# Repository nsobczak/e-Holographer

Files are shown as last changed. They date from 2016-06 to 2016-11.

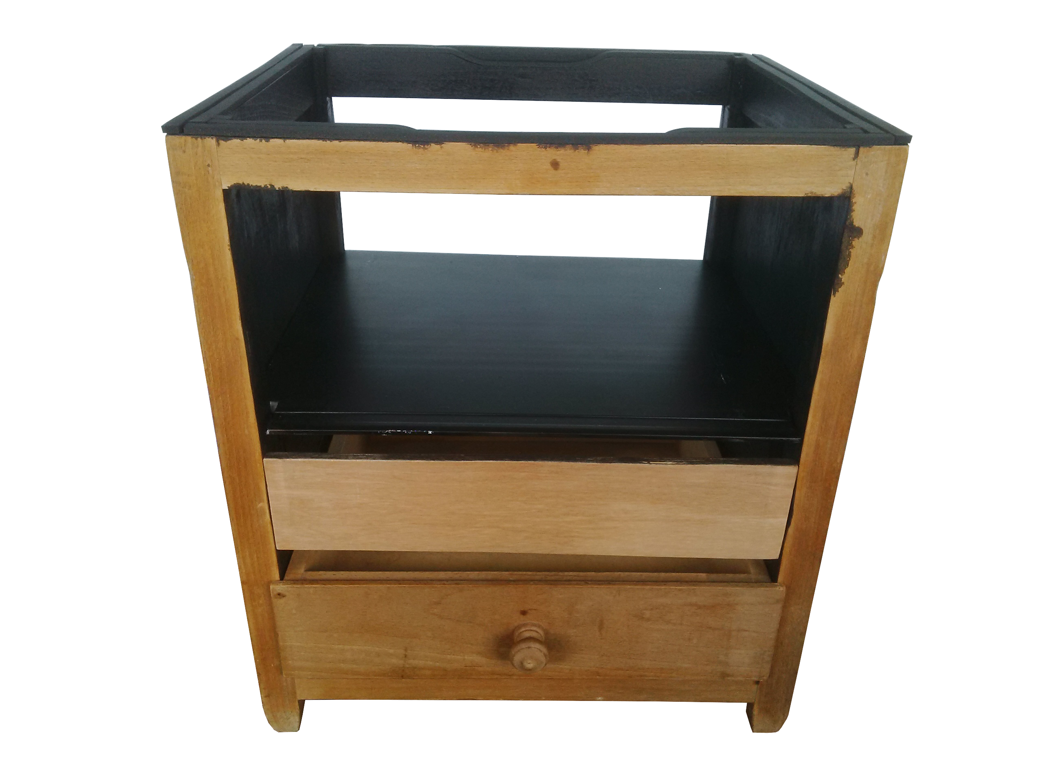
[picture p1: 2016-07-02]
Images/Armature e-Holographer.png

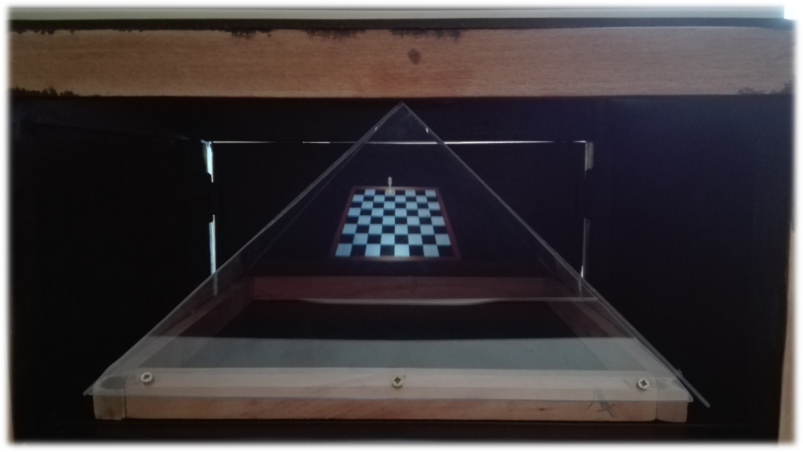
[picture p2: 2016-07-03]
Images/ChessGame/JeuDechec.jpg

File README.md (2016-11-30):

# e-Holographer

Le e-Holographer est un objet connecté permettant d'afficher des hologrammes. Il peut être intégré dans toutes sortes d'applications. Nous avons choisi de développer un jeu d'échec pour le mettre en avant les possibilités de notre e-Holographer. 

Pour plus d'informations, un [wiki](https://github.com/nsobczak/e-Holographer/wiki) est disponible

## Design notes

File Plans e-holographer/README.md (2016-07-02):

#Plans

Nous avons utilisé le logiciel Solidworks pour modéliser notre e-Holographer et générer les plans nécessaires à sa construction.

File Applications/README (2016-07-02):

Ce dossier est destiné à accueillir toutes les applications du e-Holographer.

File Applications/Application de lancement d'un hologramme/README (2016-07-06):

Dossier de l'application du tuto : lancement d'un hologramme.

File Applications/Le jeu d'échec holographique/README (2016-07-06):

Dossier de l'application jeu d'échec holographique.

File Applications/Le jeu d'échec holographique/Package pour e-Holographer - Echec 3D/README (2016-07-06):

Package constellation à déployer sur la sentinelle e-Holographer.

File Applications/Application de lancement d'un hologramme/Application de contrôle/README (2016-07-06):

Application de contrôle. Il s'agit d'une application Androïd créé avec Cordova.

Les scripts se trouvent dans le dossier "www"
L'apk se trouve dans platforms/android/build/outputs/apk

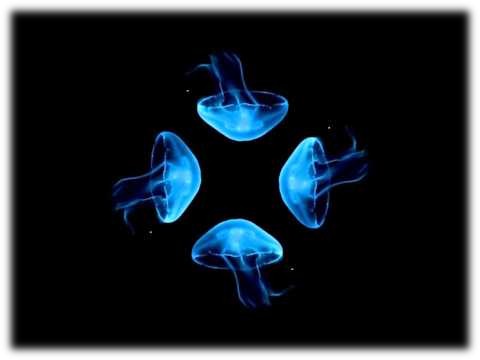
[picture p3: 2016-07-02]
Images/ImageMeduse.jpg

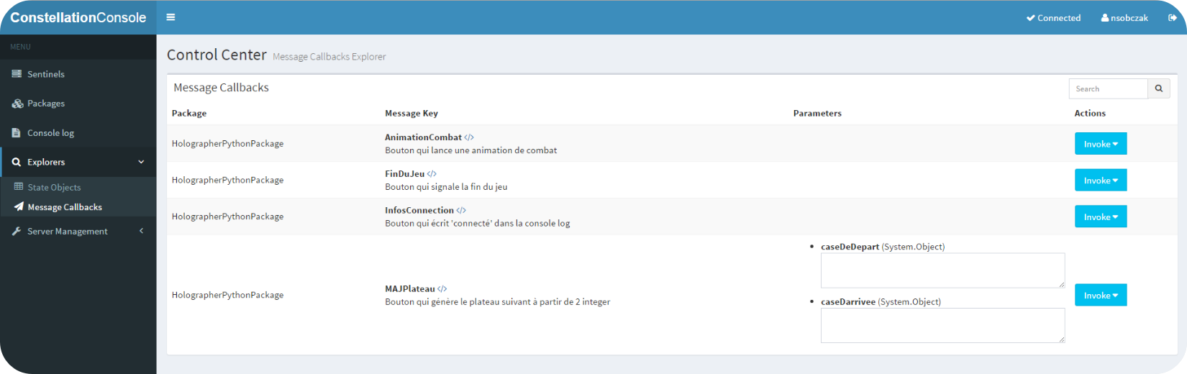
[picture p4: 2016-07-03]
Images/ChessGame/Capture_ConstellationConsole_MC.png

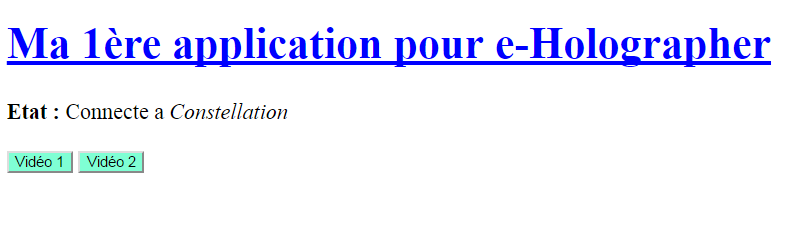
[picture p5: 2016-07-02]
Images/Ma 1ère application pour e-Holographer.PNG

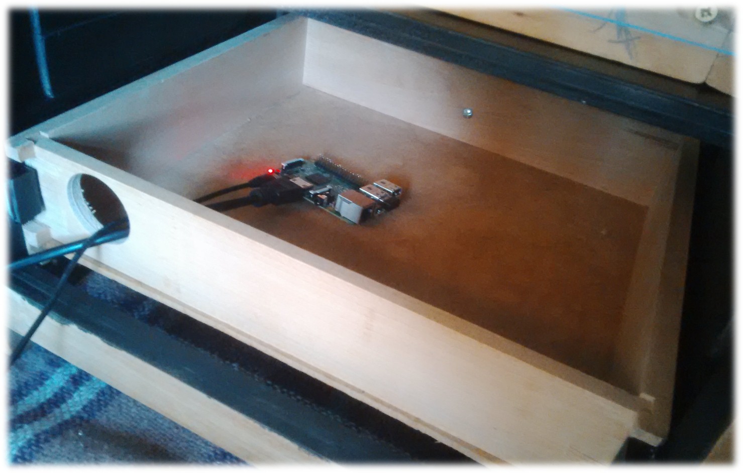
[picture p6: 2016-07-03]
Images/Tiroir avec Rpi.jpg

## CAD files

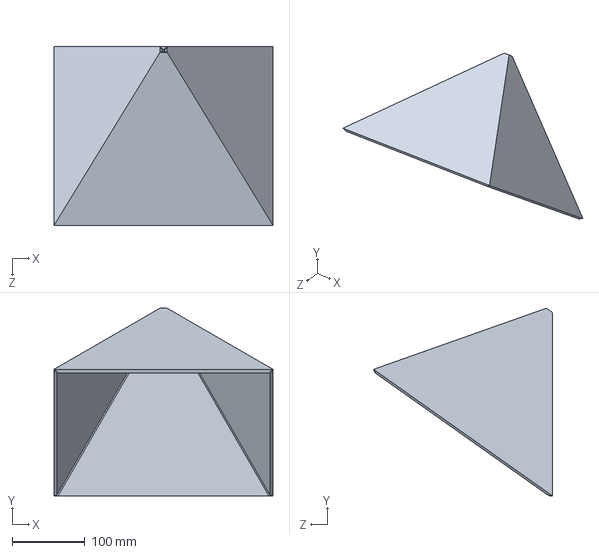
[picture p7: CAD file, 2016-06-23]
Plans e-holographer/Pyramide.SLDASM
300.0 x 256.9 x 244.9 mm
FacePyramideFini x 4

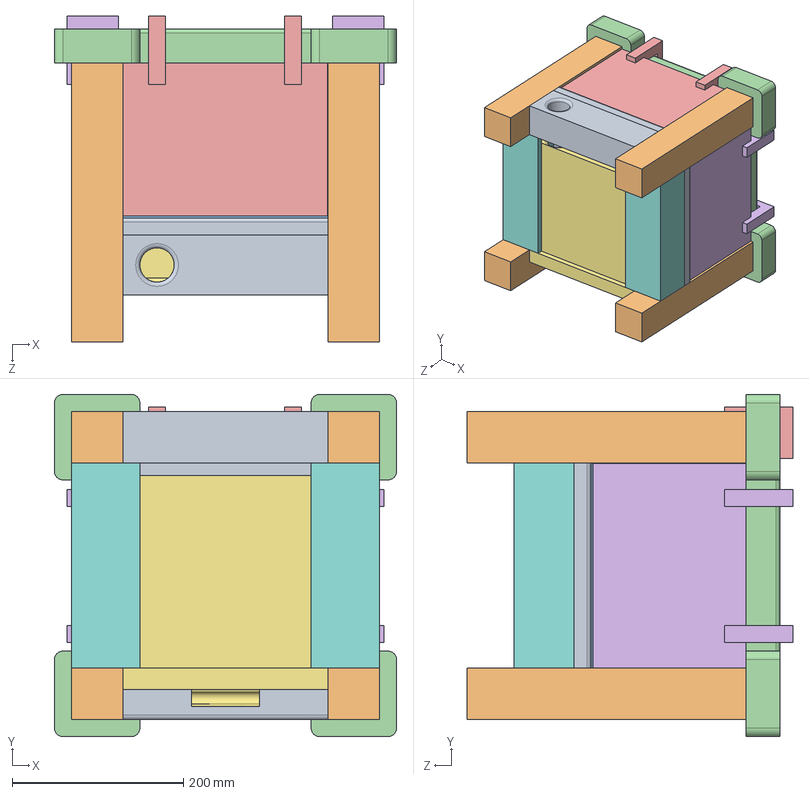
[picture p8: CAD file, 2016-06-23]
Plans e-holographer/Structure5.SLDASM
400.0 x 400.0 x 381.0 mm
Platforme
Patte x 4
FacePyramideFini x 4
Socle2
FaceLarge
FaceCourte x 2
Tirroir
TirroirC x 2
TirroirF

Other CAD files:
Applications/Le jeu d'échec holographique/Package pour e-Holographer - Echec 3D/Blender_2_64_chess.blend

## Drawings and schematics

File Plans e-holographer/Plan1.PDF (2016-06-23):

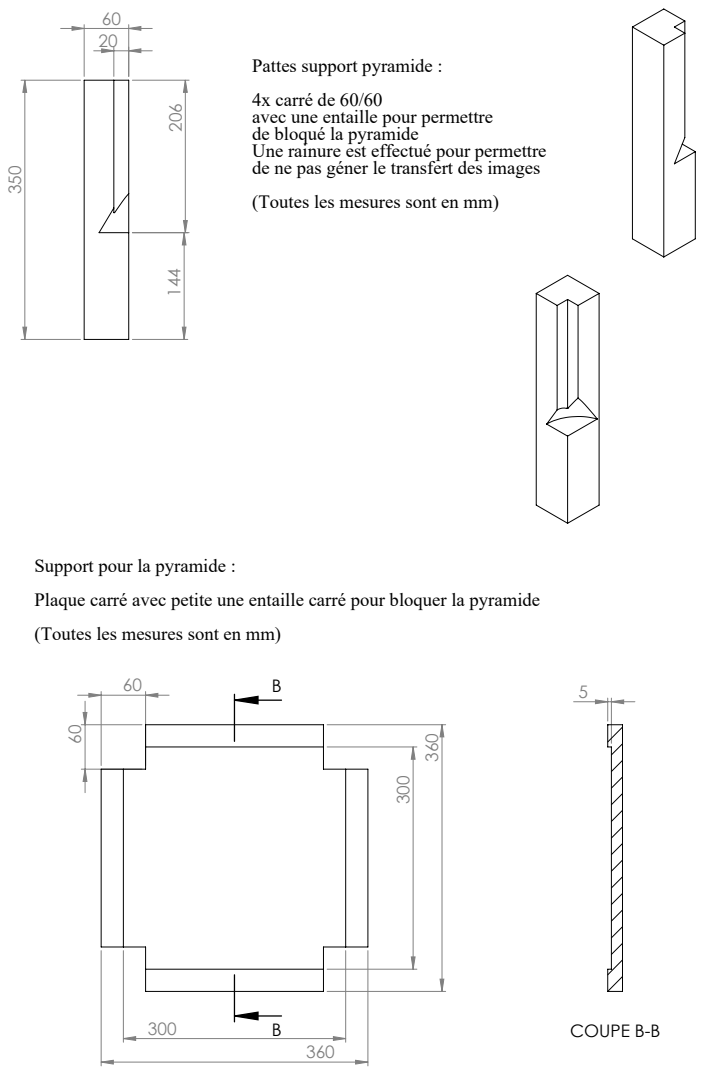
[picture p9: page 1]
COUPE B-B

Pattes support pyramide :
4x carré de 60/60
avec une entaille pour permettre
de bloqué la pyramide
Une rainure est effectué pour permettre
de ne pas géner le transfert des images
(Toutes les mesures sont en mm)

Support pour la pyramide :
Plaque carré avec petite une entaille carré pour bloquer la pyramide

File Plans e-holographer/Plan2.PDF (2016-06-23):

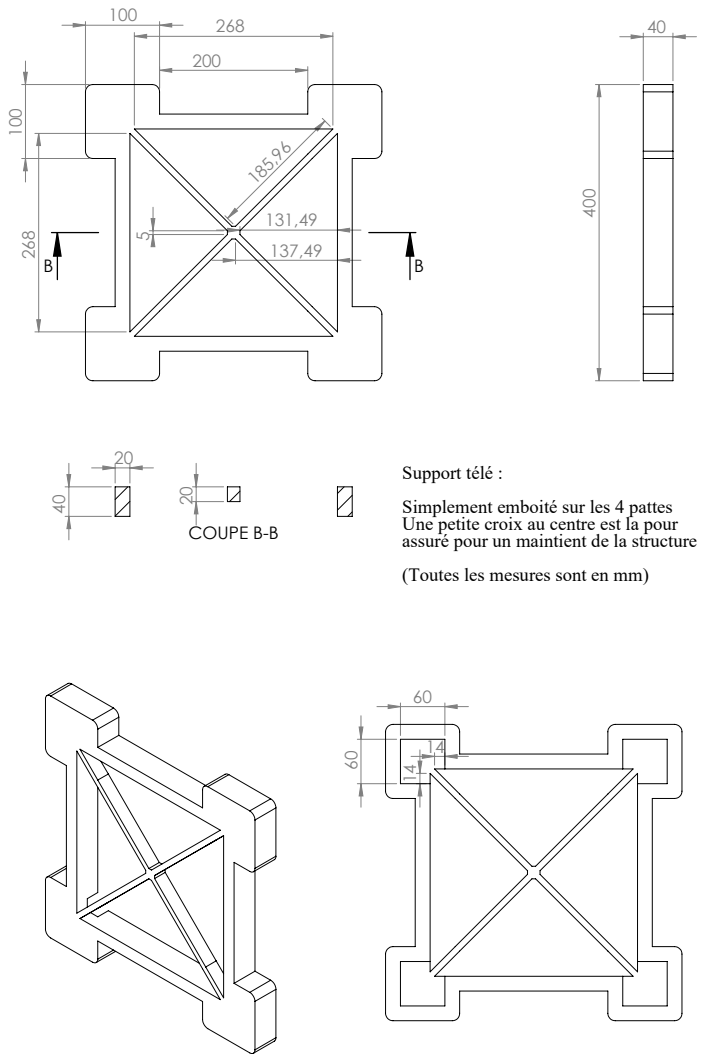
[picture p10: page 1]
COUPE B-B

Support télé :
Simplement emboité sur les 4 pattes
Une petite croix au centre est la pour
assuré pour un maintient de la structure
(Toutes les mesures sont en mm)

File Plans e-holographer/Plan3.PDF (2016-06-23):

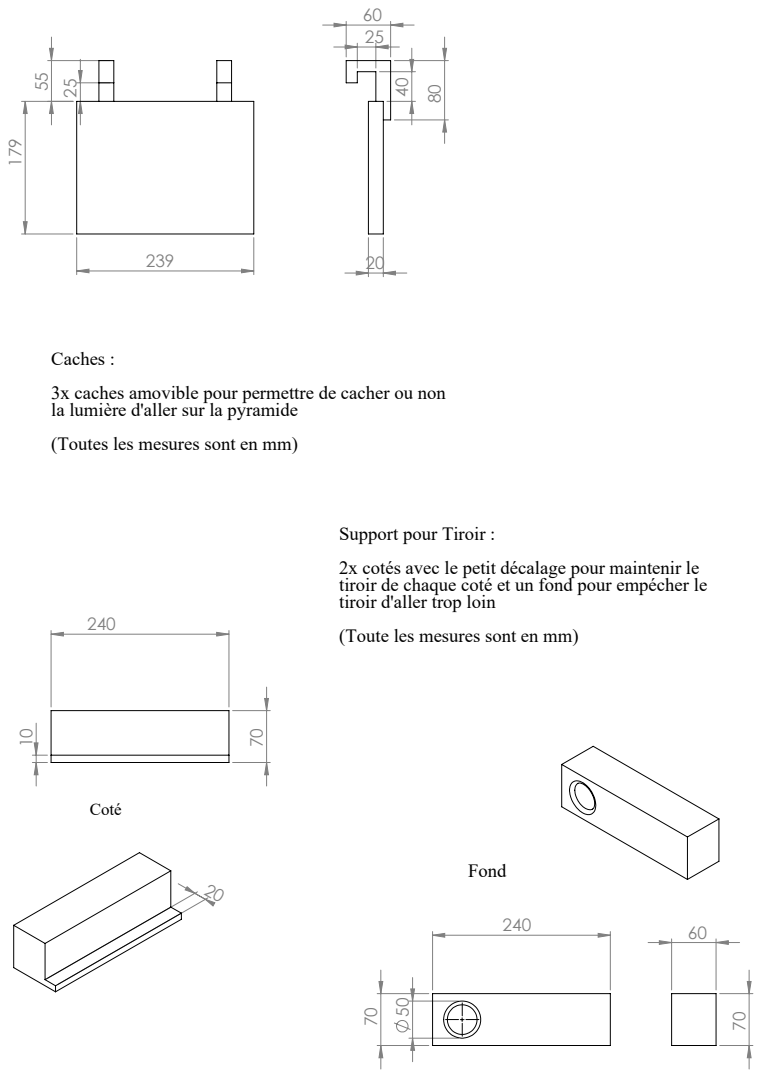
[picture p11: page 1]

Caches :
3x caches amovible pour permettre de cacher ou non
la lumière d'aller sur la pyramide
(Toutes les mesures sont en mm)

Support pour Tiroir :
2x cotés avec le petit décalage pour maintenir le
tiroir de chaque coté et un fond pour empécher le
tiroir d'aller trop loin
(Toute les mesures sont en mm)

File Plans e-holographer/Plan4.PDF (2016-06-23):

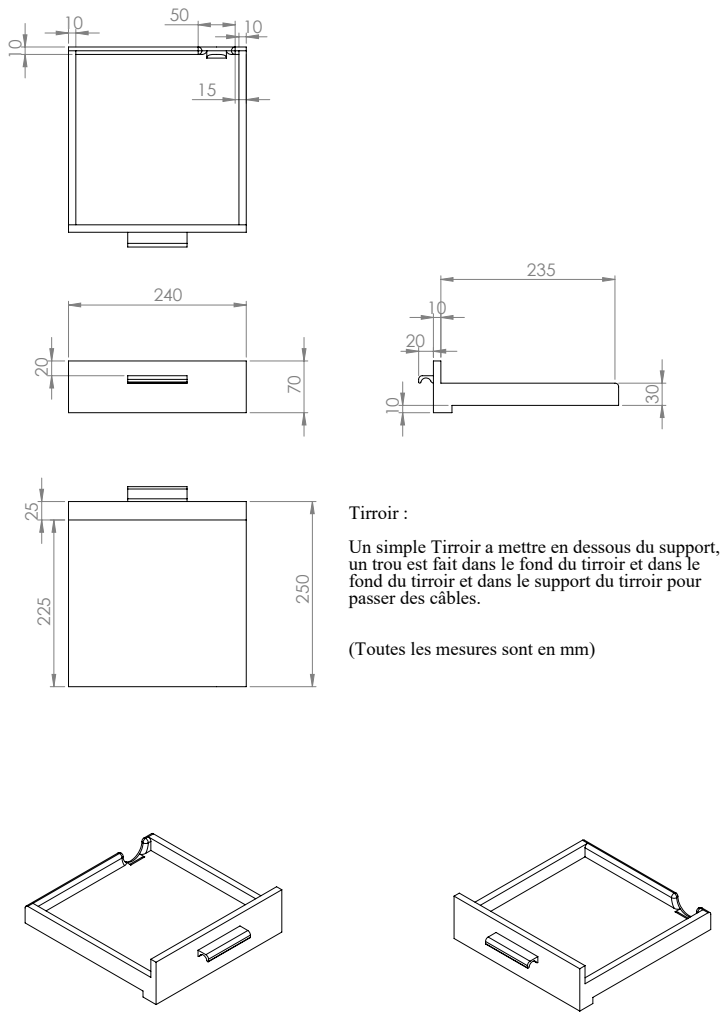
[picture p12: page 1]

Tirroir :
Un simple Tirroir a mettre en dessous du support,
un trou est fait dans le fond du tirroir et dans le
fond du tirroir et dans le support du tirroir pour
passer des câbles.

(Toutes les mesures sont en mm)

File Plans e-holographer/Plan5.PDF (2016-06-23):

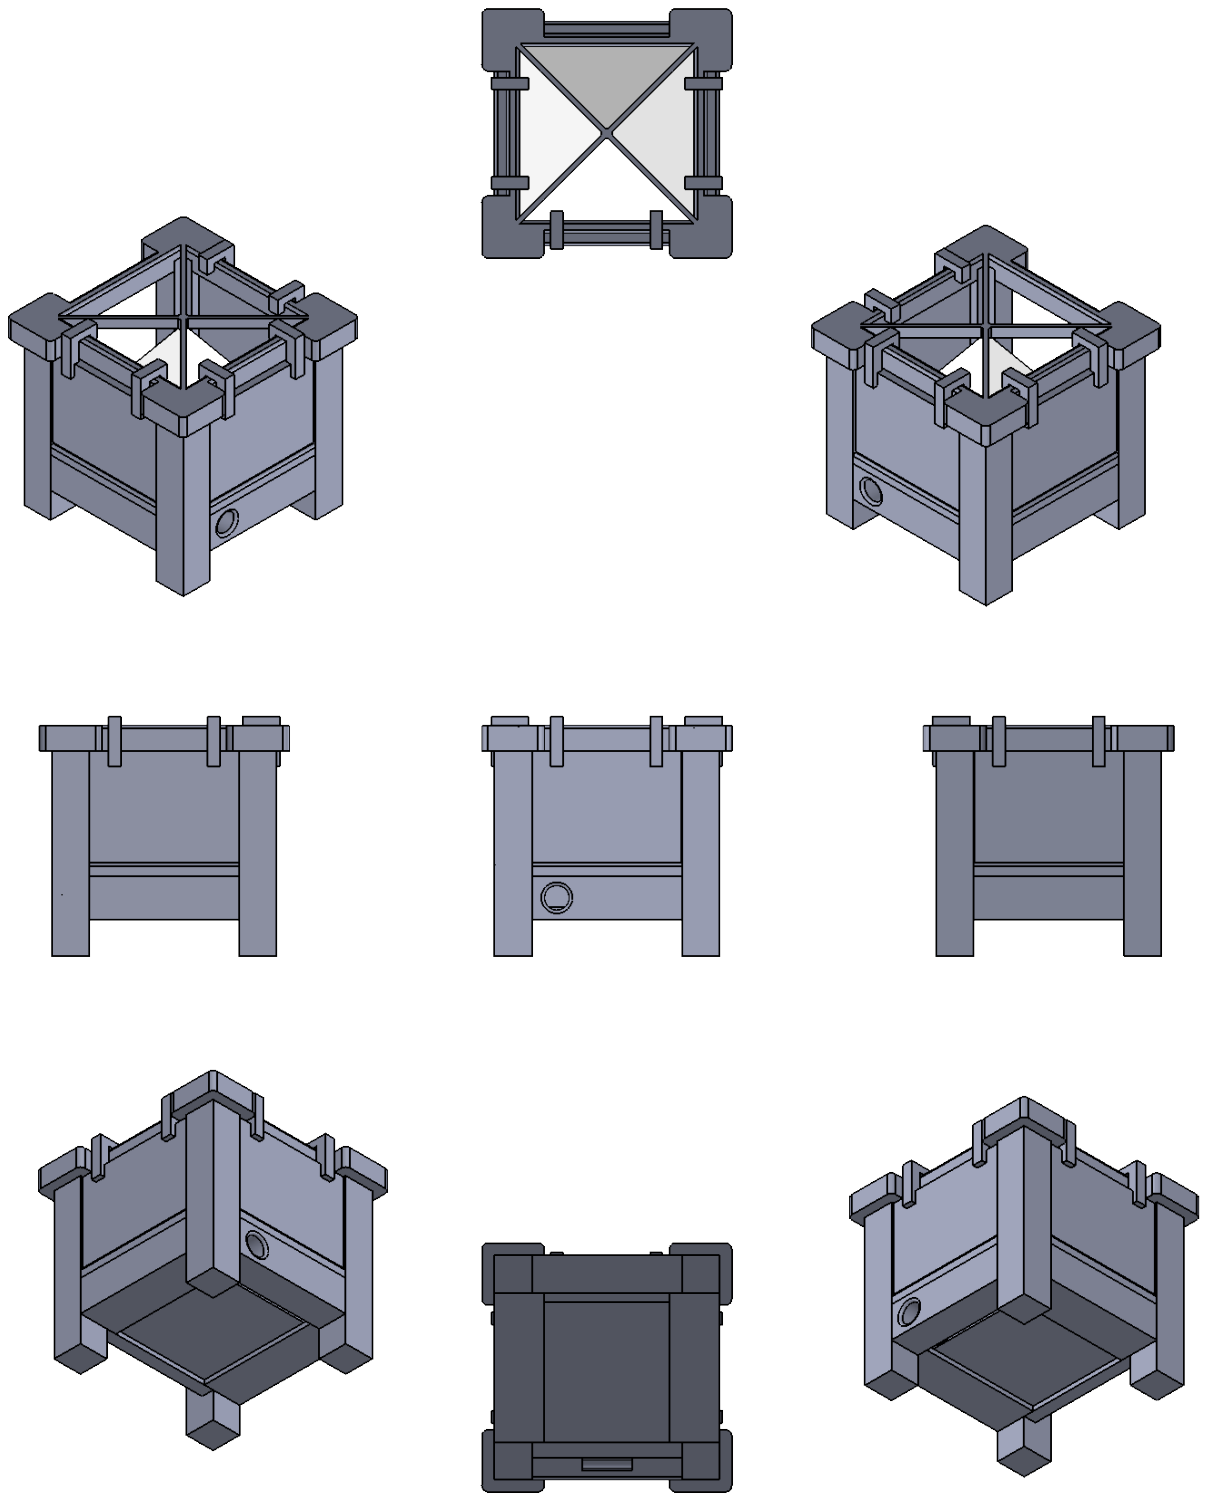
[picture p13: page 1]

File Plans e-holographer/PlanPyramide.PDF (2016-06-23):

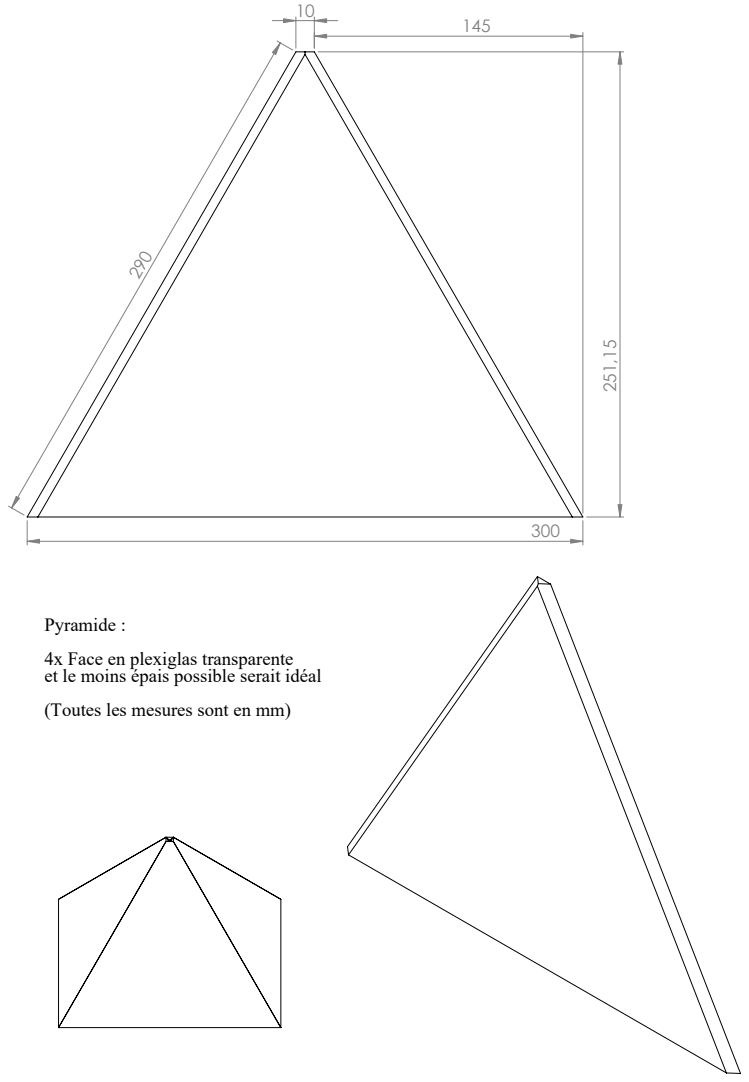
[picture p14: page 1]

Pyramide :
4x Face en plexiglas transparente
et le moins épais possible serait idéal
(Toutes les mesures sont en mm)

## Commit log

2016-05-26 Update README.md
    Ajout des 3 grandes étapes du projet
2016-06-06 Ajout de fichiers
    - modélisation 3D du plateau et des pièces avec Blender
    - jeu 2D HTML/JS
    Ajout des fichiers en vrac, pas de dossier crées
    [Blender_2_60_chess.blend]
2016-06-06 Update README.md
    Ajout de la description du serveur
2016-06-09 Ajout fichiers Cordova
    Ajout des fichiers nécessaire à la création de l'application 2D js transformé en androïd avec Cordova
2016-06-13 Delete Blender_2_60_chess.blend
    Suppression pour maj
    [Blender_2_60_chess.blend]
2016-06-13 Add files via upload
    - Ajout du script python
    - Maj de la modélisation avec blender
    [Blender_2_63_chess(pions_invisibles).blend]
2016-06-15 Ajout FusionImagesCreationPlateau.py
    Maj de FusionImagesCreationPlateau.py
2016-06-16 Ajout de photos pour illustrer le wiki
    Ajout de photos pour illustrer le wiki
2016-06-16 Ajout scripts contrôle Rpi
    Ajout des scripts de contrôle de la Raspberry (lecture image/vidéo)
2016-06-17 Ajout ChessGame
    Ajout d'une première version du jeu d'échec connecté à constellation.
    La page d'accueil se connecte à constellation et redirige vers la page de jeu. La page de jeu n'est a priori pas connectée.
    Projet visual studio.
2016-06-18 Ajout Rendus Blender
    - Ajout des images correspondant au plateau vide
    - Ajout des images correspondant au pion blanc
2016-06-18 MAJ FusionImagesCreationPlateau.py
    MAJ FusionImagesCreationPlateau.py
    Le script fait maintenant le montage des 4 images
2016-06-19 MAJ rendus pieces
    Ajout des rendus WhiteKnight
2016-06-21 Create README
    Où placer les photos une fois dézippées
2016-06-21 Ajout Plans Pyramide
    Ajout des plans de construction de la pyramide et son armature
    [Pyramide.SLDASM, Structure5.SLDASM]
2016-06-21 Create README
    Plans créés à partir de Solidworks
2016-06-22 Ajout jeu d'échec
    Ajout jeu d'échec avec connexion simple à Constellation.
    - Affiche l'état de la connesion au serveur (connecté ou non) sur la page
    - Ecrit un message dans le log
2016-06-23 MAJ index.html
    Ajout de l'envoi du message Callback de MAJ du plateau de jeu quand une pièce est déplacée
2016-06-23 MAJ chess.js
    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
2016-06-23 Suppression des identifiants
    Suppression des identifiants du serveur. Ils sont à remplacer par le serveur auquel on souhaite se connecter.
2016-06-23 Update README.md
    MAJ de la partie Intégration
2016-06-23 MAJ rendus pieces
    Ajout des rendus WhiteQueen
2016-06-23 MAJ FusionImagesCreationPlateau.py
    Correction de la mauvaise création du plateau selon certaines orientations
2016-06-24 MAJ FusionImagesCreationPlateau.py
    Ajout de commentaires sur les orientations
2016-06-24 Update README.md
    Ajout de la description du e-Holographer
2016-06-25 Corrections
    Corrections de :
    - l'indentation sur github (car elle a été altérée)
    - la fonction imagesPlateauInitial (la liste des positions des pièces été erronée)
    - la fonction creeImageHolographique est renommée regroupe4ImagesEn1 et un "+1" intempestif a été retiré
2016-06-25 MAJ chess.js
    Ajout de sendMessage car MAJ du package
2016-06-25 MAJ Echec 3D - hologramme
    - Ajout du package
    - Inclusion des anciens scripts dans le package
    - MAJ du blender
    [Blender_2_64_chess(débutPriseImages).blend]
2016-06-25 Delete Blender_2_63_chess(pions_invisibles).blend
    MAJ
    [Blender_2_63_chess(pions_invisibles).blend]
2016-06-27 Update Holographer.py
    Suppression des identifiants des serveurs
2016-06-27 MAJ rendus pieces
    Ajout rendus BlackQueen et BlackPawn nécessaire à la réalisation du scénario de la présentation, mais la prise des rendus n'est pas terminée.
2016-06-27 Update README.md
    Suppression de la partie "intégration"
2016-06-29 Ajout photos
    Ajout pour MAJ avec le nom des photos
2016-06-29 Corrections -> dernière version sans bug
    Correction de plusieurs fonction dont principalement celle qui associe un numéro de case à un entier
2016-06-30 Update FusionImagesCreationPlateau.py
    Modification des commentaires en toute fin du fichier :
    - suppression des "trucs à faire"
    - ajout de remarques
2016-06-30 Update index.html
    Suppression des informations relatives au serveur constellation => à remplacer par le serveur auquel on souhaite se connecter.
2016-06-30 Ajout res
    Ajout du dossier res de Cordova
2016-06-30 Delete android-debug.apk
    Delete car ajout de platform.zip qui contient déjà l'apk
2016-06-30 Ajout application Cordova
    Ajout application Cordova de lancement d'une vidéo hologramme
2016-07-01 Réorganisation des dossiers
    Réorganisation des dossiers :
    - Applications : 1ère appli + jeu d'échec
    [Blender_2_64_chess(débutPriseImages).blend]
2016-07-01 Réorganisation et renommage des dossiers
    Réorganisation et renommage des dossiers
    [Blender_2_64_chess.blend, Pyramide.SLDASM, Structure5.SLDASM]
2016-07-02 modifications rendre variables global
    rendre les variables nécessaires global en le précisant en début de fonction
2016-07-02 globaliser certaines variables /!\ il reste modif
    mise de IdProcI en global mais il en reste comme cheminScriptImage à mettre en global
2016-07-06 Update README
    "Appli de contrôle"
2016-07-06 Update README
    Localisation des script dans www
